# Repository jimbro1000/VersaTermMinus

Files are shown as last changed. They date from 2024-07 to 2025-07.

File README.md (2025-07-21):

# VersaTermMinus

Reduced and simplified version of David Hansel's VersaTerm
project [github.com/dhansel/VersaTerm](https://github.com/dhansel/VersaTerm)

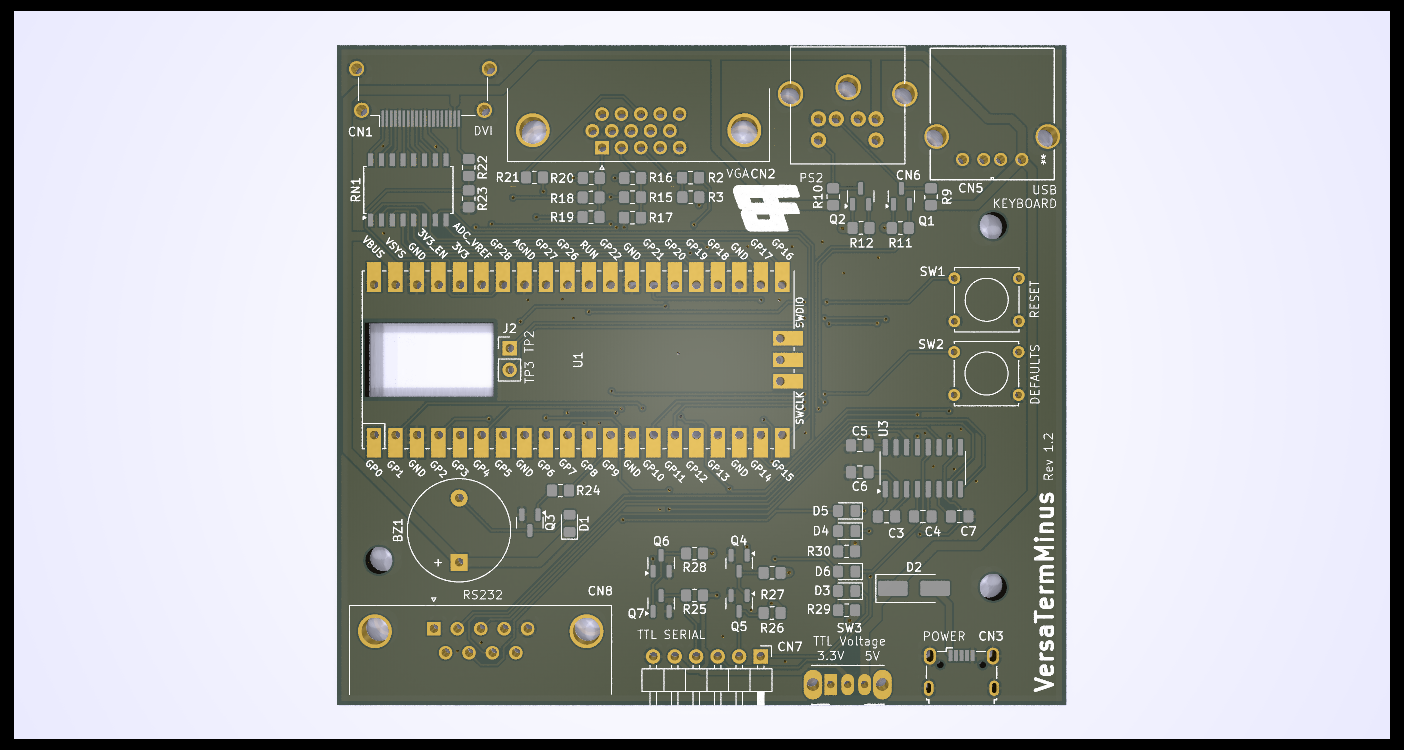
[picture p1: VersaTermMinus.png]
render of VersaTermMinus PCB


You can order PCBs for this project direct from PCBWay's shared projects
(https://www.pcbway.com/project/shareproject/VersaTermMinus_d8ad71ad.html)

## Changes to the Original Design

There are four significant changes to the board:

1. The barrel-jack power supply connection is deleted
2. The USB socket for keyboard is now micro-USB
3. The MAX3232 is integrated into the board
4. Where possible components are SMD

The changes allow the board to be reduced in size and cost.

## Assembly

It is highly recommended to use a stencil and
hot plate for mounting the SMD components. If
assembling by hand, start with the MAX232 chip
and resistor pack. It is important to mount the
small resistors, capacitors and diodes before
adding the HDMI, USB and large through-hole
components. Failing to do those first will make
assembly much harder.

If you want to use the USB keyboard option a
pair of wires needs to be attached to TP2 and
TP3 on the underside of the Pico board, and
connected to the J2 position on the main board.
Pin 1 of J2 should be connected to TP2.

### 1n4148 Diodes

The board uses a regular 0805 footprint for the
smaller 1n4148 diodes but it may prove easier
to source SOD323. These still fit easily on the
0805 footprint.

## Firmware

The pico board should be loaded with the 
original VersaTerm firmware from David Hansel's
git repository: [VersaTerm uf2 firmware](https://github.com/dhansel/VersaTerm/blob/main/software/VersaTerm.uf2)

## Errors on Early Fabricated Boards

On the first run of the board the traces to
the RS232 DE9 connector were incorrect. To fix
the error it is necessary to cut three of the
traces running from the MAX232 chip to the DE9.

With the DE9 nearest you the top three diagonal
traces running from top right to bottom left
need to be cut.

Three wires then need soldering to the upper two
pins of the DE9 and the lower middle (Pins 2, 3
and 8 of the connector). These need to be wired
to the MAX3232 on pins 5, 15 and 16.

DE9 pin 8 -> MAX3232 pin 16  
DE9 pin 2 -> MAX3232 pin 5  
DE9 pin 3 -> MAX3232 pin 15

To keep the fix tidy I drilled a hold through
the PCB above the right hand edge of the DE9
and below the visible traces on the top of the
board. This allows shorter, more direct
connections to be made.

A second fault exists within the buzzer circuit.
The polarity marking for the buzzer is reversed
(just fit the buzzer back to front). The transistor
switching the buzzer is also incorrect. To fix this
the transistor needs rotating around the top left 
pad (pin 2) such that the top right pin (1) sits on
the bottom pad. A wire needs to be run from the now
loose pin of the transistor (pin 3) to the negative
side of the buzzer, the vacant transistor pad or
the top pad of D1. The trace running from transistor
to the buzzer could be exposed to allow a solder 
bridge to be created

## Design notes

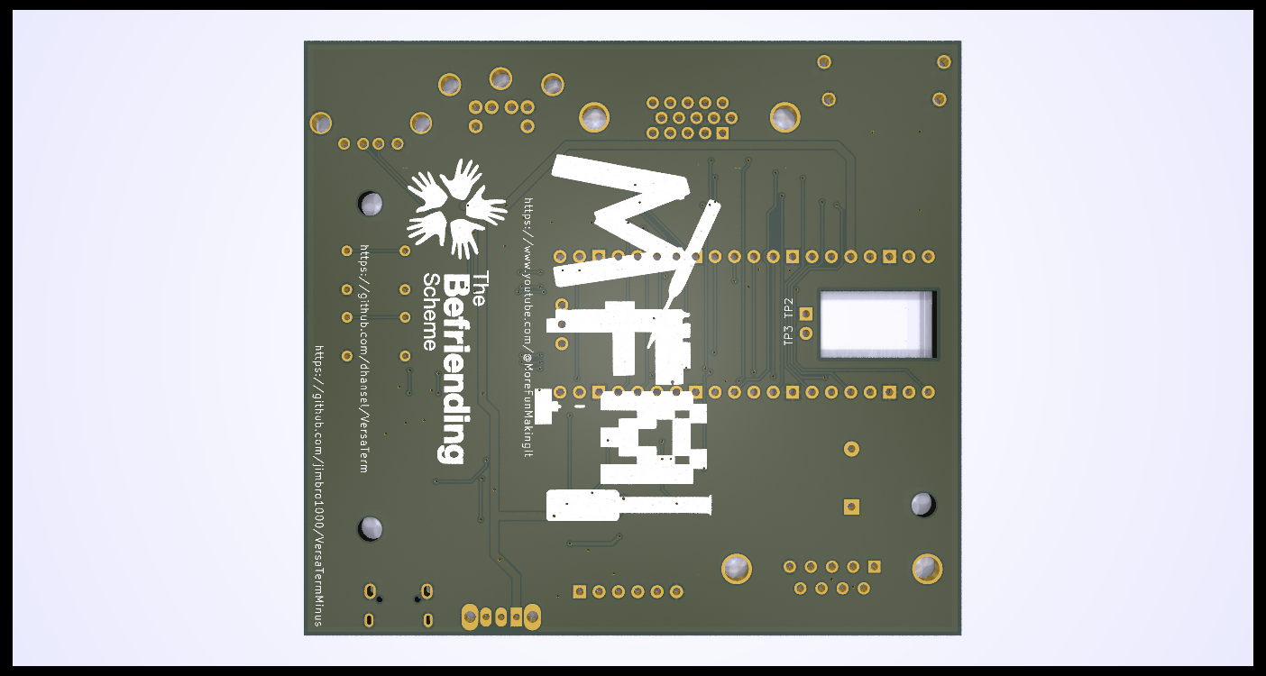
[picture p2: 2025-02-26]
VersaTermMinusBack.png

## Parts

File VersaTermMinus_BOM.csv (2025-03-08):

Reference | Value | Datasheet | Footprint | Qty | DNP
BZ1 | Buzzer | ~ | Buzzer_Beeper:Buzzer_12x9.5RM7.6 | 1
C3,C4,C5,C6,C7 | 100nF | ~ | Capacitor_SMD:C_0805_2012Metric_Pad1.18x1.45mm_HandSolder | 5
CN1 | HDMI_A | https://en.wikipedia.org/wiki/HDMI | Connector_HDMI:HDMI_A_Amphenol_10029449-x01xLF_Horizontal | 1
CN2 | DE15_Socket | ~ | Connector_Dsub:DSUB-15-HD_Female_Horizontal_P2.29x1.98mm_EdgePinOffset3.03mm_Housed_MountingHolesOffset4.94mm | 1
CN3 | USB_B_Micro | https://www.we-online.com/katalog/datasheet/629105150521.pdf | Connector_USB:USB_Micro-B_Wuerth_629105150521 | 1
CN5 | USB-A | 676432911 | Connector_USBA_Molex:CONN_67643-2911_MOL | 1
CN6 | Mini-DIN-6 | http://service.powerdynamics.com/ec/Catalog17/Section%2011.pdf | Connector_Mini_DIN:KMDGX-6S-N | 1
CN7 | TTL Serial | ~ | Connector_PinHeader_2.54mm:PinHeader_1x06_P2.54mm_Horizontal | 1
CN8 | DE9 Socket | ~ | Connector_Dsub:DSUB-9_Male_Horizontal_P2.77x2.84mm_EdgePinOffset4.94mm_Housed_MountingHolesOffset7.48mm | 1
D1,D3,D4,D5,D6 | 1N4148 | https://assets.nexperia.com/documents/data-sheet/1N4148_1N4448.pdf | Diode_SMD:D_0805_2012Metric_Pad1.15x1.40mm_HandSolder | 5
D2 | DBA140SL-HF | ~ | Diode_SMD:D_SMA_Handsoldering | 1
J2 | USBDATA | ~ | Connector_PinHeader_2.54mm:PinHeader_1x02_P2.54mm_Vertical | 1
Q1,Q2,Q3,Q4,Q5,Q6,Q7 | 2N7002 | https://www.onsemi.com/pub/Collateral/NDS7002A-D.PDF | Package_TO_SOT_SMD:SOT-23 | 7
R2,R17,R20,R25,R26 | 470R | ~ | Resistor_SMD:R_0805_2012Metric_Pad1.20x1.40mm_HandSolder | 5
R3,R16,R19,R27,R28,R29,R30 | 1K | ~ | Resistor_SMD:R_0805_2012Metric_Pad1.20x1.40mm_HandSolder | 7
R9,R10,R11,R12,R23 | 10K | ~ | Resistor_SMD:R_0805_2012Metric_Pad1.20x1.40mm_HandSolder | 5
R15,R18 | 2K2 | ~ | Resistor_SMD:R_0805_2012Metric_Pad1.20x1.40mm_HandSolder | 2
R21,R24 | 100R | ~ | Resistor_SMD:R_0805_2012Metric_Pad1.20x1.40mm_HandSolder | 2
R22 | 4K7 | ~ | Resistor_SMD:R_0805_2012Metric_Pad1.20x1.40mm_HandSolder | 1
RN1 | 270R | https://www.bourns.com/docs/Product-Datasheets/4800P.pdf | Package_SO:SOIC-16W_5.3x10.2mm_P1.27mm | 1
SW1 | RESET | https://www.ckswitches.com/media/1457/ksa_ksl.pdf | Button_Switch_THT:SW_Tactile_Straight_KSA0Axx1LFTR | 1
SW2 | DEFAULTS | https://www.ckswitches.com/media/1457/ksa_ksl.pdf | Button_Switch_THT:SW_Tactile_Straight_KSA0Axx1LFTR | 1
SW3 | 3V3/5V | https://www.ckswitches.com/media/1428/os.pdf | Button_Switch_THT:SW_Slide_SPDT_Angled_CK_OS102011MA1Q | 1
U1 | Raspberry Pi Pico |  | MCU_RaspberryPi_and_Boards:RPi_Pico_SMD_TH | 1
U3 | MAX3232 | https://datasheets.maximintegrated.com/en/ds/MAX3222-MAX3241.pdf | Package_SO:SOIC-16_3.9x9.9mm_P1.27mm | 1

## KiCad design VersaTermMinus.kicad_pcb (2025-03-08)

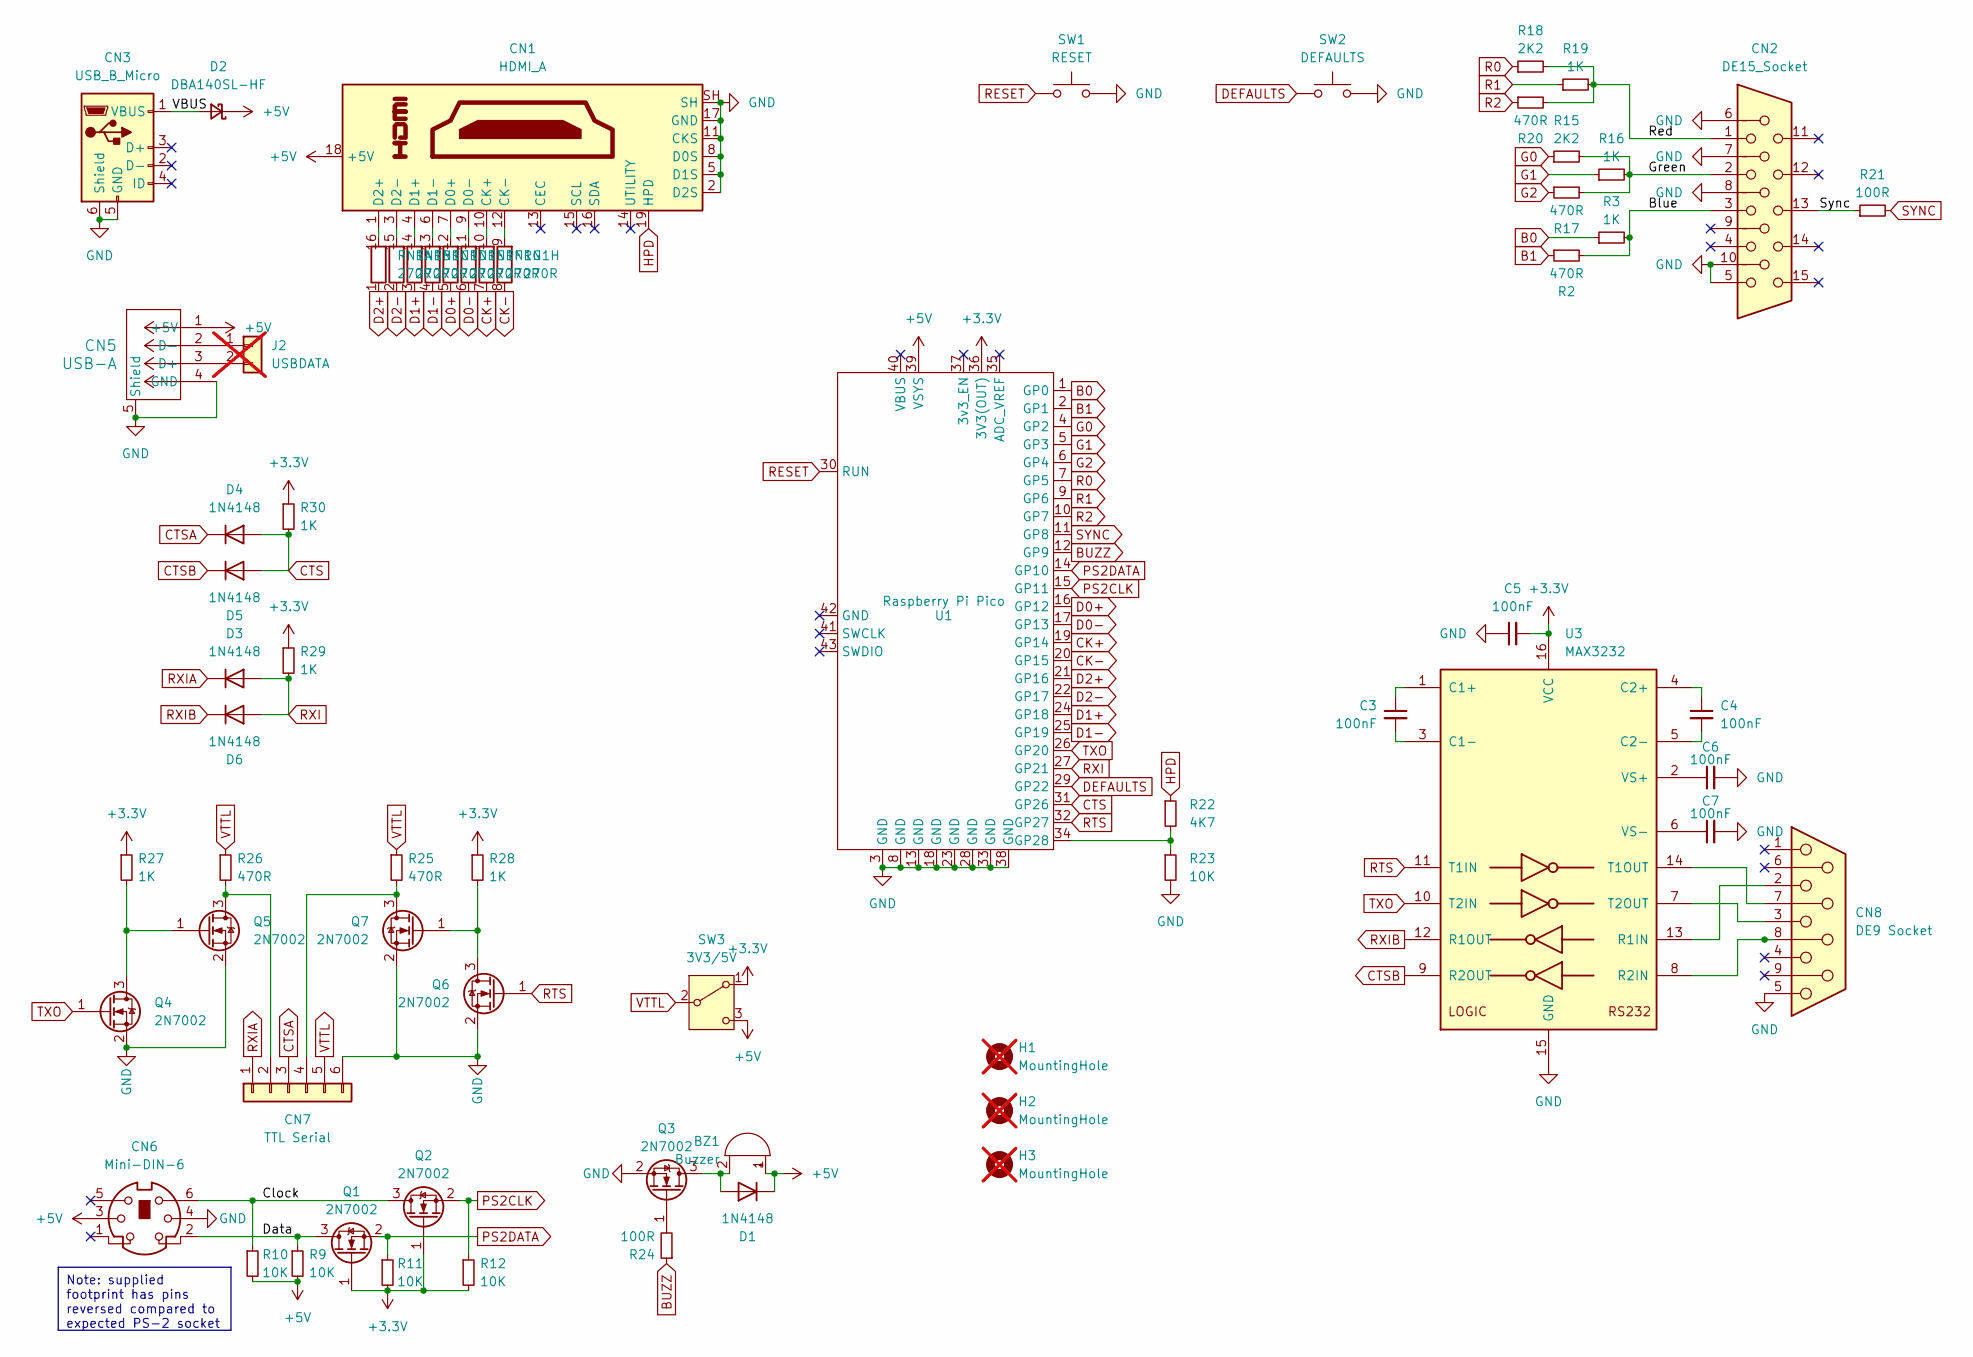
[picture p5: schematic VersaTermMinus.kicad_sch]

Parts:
BZ1: Buzzer; Buzzer_12x9.5RM7.6; LCSC C96491
C3, C4, C5, C6, C7: 100nF; C_0805_2012Metric_Pad1.18x1.45mm_HandSolder; DigiKey 311-1140-1-ND
CN1: HDMI_A; HDMI_A_Amphenol_10029449-x01xLF_Horizontal; DigiKey 609-4614-1-ND
CN2: DE15_Socket; DSUB-15-HD_Female_Horizontal_P2.29x1.98mm_EdgePinOffset3.03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; DigiKey L77HDE15SD1CH4FVGA-ND
CN3: USB_B_Micro; USB_Micro-B_Wuerth_629105150521; DigiKey 732-5960-1-ND
CN5: USB-A; CONN_67643-2911_MOL; DigiKey WM4078-ND
CN6: Mini-DIN-6; KMDGX-6S-N; DigiKey 2092-KMDGX-6S-BS-ND
CN7: TTL Serial; PinHeader_1x06_P2.54mm_Horizontal; LCSC C492414
CN8: DE9 Socket; DSUB-9_Male_Horizontal_P2.77x2.84mm_EdgePinOffset4.94mm_Hou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; DigiKey AE10968-ND
D1, D3, D4, D5, D6: 1N4148; D_0805_2012Metric_Pad1.15x1.40mm_HandSolder; DigiKey 1N4148WXTPMSCT-ND
D2: DBA140SL-HF; D_SMA_Handsoldering; DigiKey 641-1762-1-ND
H1, H2, H3: MountingHole; MountingHole_3.2mm_M3; not fitted
J2: USBDATA; PinHeader_1x02_P2.54mm_Vertical; not fitted
Q1, Q2, Q3, Q4, Q5, Q6, Q7: 2N7002; SOT-23; DigiKey 2N7002NCT-ND
R2, R17, R20, R25, R26: 470R; R_0805_2012Metric_Pad1.20x1.40mm_HandSolder; DigiKey RMCF0805FT470RCT-ND
R3, R16, R19, R27, R28, R29, R30: 1K; R_0805_2012Metric_Pad1.20x1.40mm_HandSolder; LCSC C95781
R9, R10, R11, R12, R23: 10K; R_0805_2012Metric_Pad1.20x1.40mm_HandSolder; LCSC C17414
R15, R18: 2K2; R_0805_2012Metric_Pad1.20x1.40mm_HandSolder; LCSC C17520
R21, R24: 100R; R_0805_2012Metric_Pad1.20x1.40mm_HandSolder; LCSC C105577
R22: 4K7; R_0805_2012Metric_Pad1.20x1.40mm_HandSolder; LCSC C17673
RN1: 270R; SOIC-16W_5.3x10.2mm_P1.27mm; DigiKey 4816P-1-271LFCT-ND
SW1: RESET; SW_Tactile_Straight_KSA0Axx1LFTR; DigiKey CKN10734-ND
SW2: DEFAULTS; SW_Tactile_Straight_KSA0Axx1LFTR; DigiKey CKN10734-ND
SW3: 3V3/5V; SW_Slide_SPDT_Angled_CK_OS102011MA1Q; DigiKey CKN9559-ND
U1: Raspberry Pi Pico; RPi_Pico_SMD_TH
U3: MAX3232; SOIC-16_3.9x9.9mm_P1.27mm; DigiKey 296-13094-1-ND

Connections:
+3.3V: C5.2, Q1.1 (G), Q2.1 (G), R11.2, R12.2, R27.1, R28.1, R29.1, R30.1, SW3.1 (A), U1.36 (3V3(OUT)), U3.16 (VCC)
+5V: BZ1.1 (+), CN1.18 (+5V), CN5.1 (+5V), CN6.3, D1.1 (K), D2.1 (K), R9.2, R10.2, SW3.3 (C), U1.39 (VSYS)
/Blue: CN2.3, R2.2, R3.2
/Clock: CN6.6, Q2.3 (D), R10.1
/Data: CN6.2, Q1.3 (D), R9.1
/Green: CN2.2, R15.2, R16.2, R17.2
/Red: CN2.1, R18.2, R19.2, R20.2
/Sync: CN2.13, R21.1
/VBUS: CN3.1 (VBUS), D2.2 (A)
B0: R3.1, U1.1 (GP0)
B1: R2.1, U1.2 (GP1)
BUZZ: R24.1, U1.12 (GP9)
CK+: RN1.7 (R7.1), U1.19 (GP14)
CK-: RN1.8 (R8.1), U1.20 (GP15)
CTS: D4.2 (A), D5.2 (A), R30.2, U1.31 (GP26)
CTSA: CN7.3, D4.1 (K)
CTSB: D5.1 (K), U3.9 (R2OUT)
D0+: RN1.5 (R5.1), U1.16 (GP12)
D0-: RN1.6 (R6.1), U1.17 (GP13)
D1+: RN1.3 (R3.1), U1.24 (GP18)
D1-: RN1.4 (R4.1), U1.25 (GP19)
D2+: RN1.1 (R1.1), U1.21 (GP16)
D2-: RN1.2 (R2.1), U1.22 (GP17)
DEFAULTS: SW2.1, U1.29 (GP22)
G0: R15.1, U1.4 (GP2)
G1: R16.1, U1.5 (GP3)
G2: R17.1, U1.6 (GP4)
GND: C5.1, C6.2, C7.2, CN1.2 (D2S), CN1.5 (D1S), CN1.8 (D0S), CN1.11 (CKS), CN1.17 (GND), CN1.SH, CN2.5, CN2.6, CN2.7, CN2.8, CN2.10, CN3.5 (GND), CN3.6 (Shield), CN5.4 (GND), CN5.5 (Shield), CN6.4, CN7.6, CN8.5, Q3.2 (S), Q4.2 (S), Q5.2 (S), Q6.2 (S), Q7.2 (S), R23.2, SW1.2, SW2.2, U1.3 (GND), U1.8 (GND), U1.13 (GND), U1.18 (GND), U1.23 (GND), U1.28 (GND), U1.33 (GND), U1.38 (GND), U3.15 (GND)
HPD: CN1.19 (HPD), R22.1
unnamed: BZ1.2 (-), D1.2 (A), Q3.3 (D)
unnamed: CN1.10 (CK+), RN1.10 (R7.2)
unnamed: CN1.12 (CK-), RN1.9 (R8.2)
unnamed: CN1.7 (D0+), RN1.12 (R5.2)
unnamed: CN1.9 (D0-), RN1.11 (R6.2)
unnamed: CN1.4 (D1+), RN1.14 (R3.2)
unnamed: CN1.6 (D1-), RN1.13 (R4.2)
unnamed: CN1.1 (D2+), RN1.16 (R1.2)
unnamed: CN1.3 (D2-), RN1.15 (R2.2)
unnamed: CN5.3 (D+), J2.2
unnamed: CN5.2 (D-), J2.1
unnamed: CN7.2, Q5.3 (D), R26.2
unnamed: CN7.4, Q7.3 (D), R25.2
unnamed: Q3.1 (G), R24.2
unnamed: Q4.3 (D), Q5.1 (G), R27.2
unnamed: Q6.3 (D), Q7.1 (G), R28.2
unnamed: R22.2, R23.1, U1.34 (GP28)
unnamed: C3.1, U3.1 (C1+)
unnamed: C3.2, U3.3 (C1-)
unnamed: C4.1, U3.4 (C2+)
unnamed: C4.2, U3.5 (C2-)
unnamed: CN8.2, U3.13 (R1IN)
unnamed: CN8.8, U3.8 (R2IN)
unnamed: CN8.7, U3.14 (T1OUT)
unnamed: CN8.3, U3.7 (T2OUT)
unnamed: C6.1, U3.2 (VS+)
unnamed: C7.1, U3.6 (VS-)
PS2CLK: Q2.2 (S), R12.1, U1.15 (GP11)
PS2DATA: Q1.2 (S), R11.1, U1.14 (GP10)
R0: R18.1, U1.7 (GP5)
R1: R19.1, U1.9 (GP6)
R2: R20.1, U1.10 (GP7)
RESET: SW1.1, U1.30 (RUN)
RTS: Q6.1 (G), U1.32 (GP27), U3.11 (T1IN)
RXI: D3.2 (A), D6.2 (A), R29.2, U1.27 (GP21)
RXIA: CN7.1, D3.1 (K)
RXIB: D6.1 (K), U3.12 (R1OUT)
SYNC: R21.2, U1.11 (GP8)
TXO: Q4.1 (G), U1.26 (GP20), U3.10 (T2IN)
VTTL: CN7.5, R25.1, R26.1, SW3.2 (B)

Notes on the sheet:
Note: supplied footprint has pins reversed compared to expected PS-2 socket

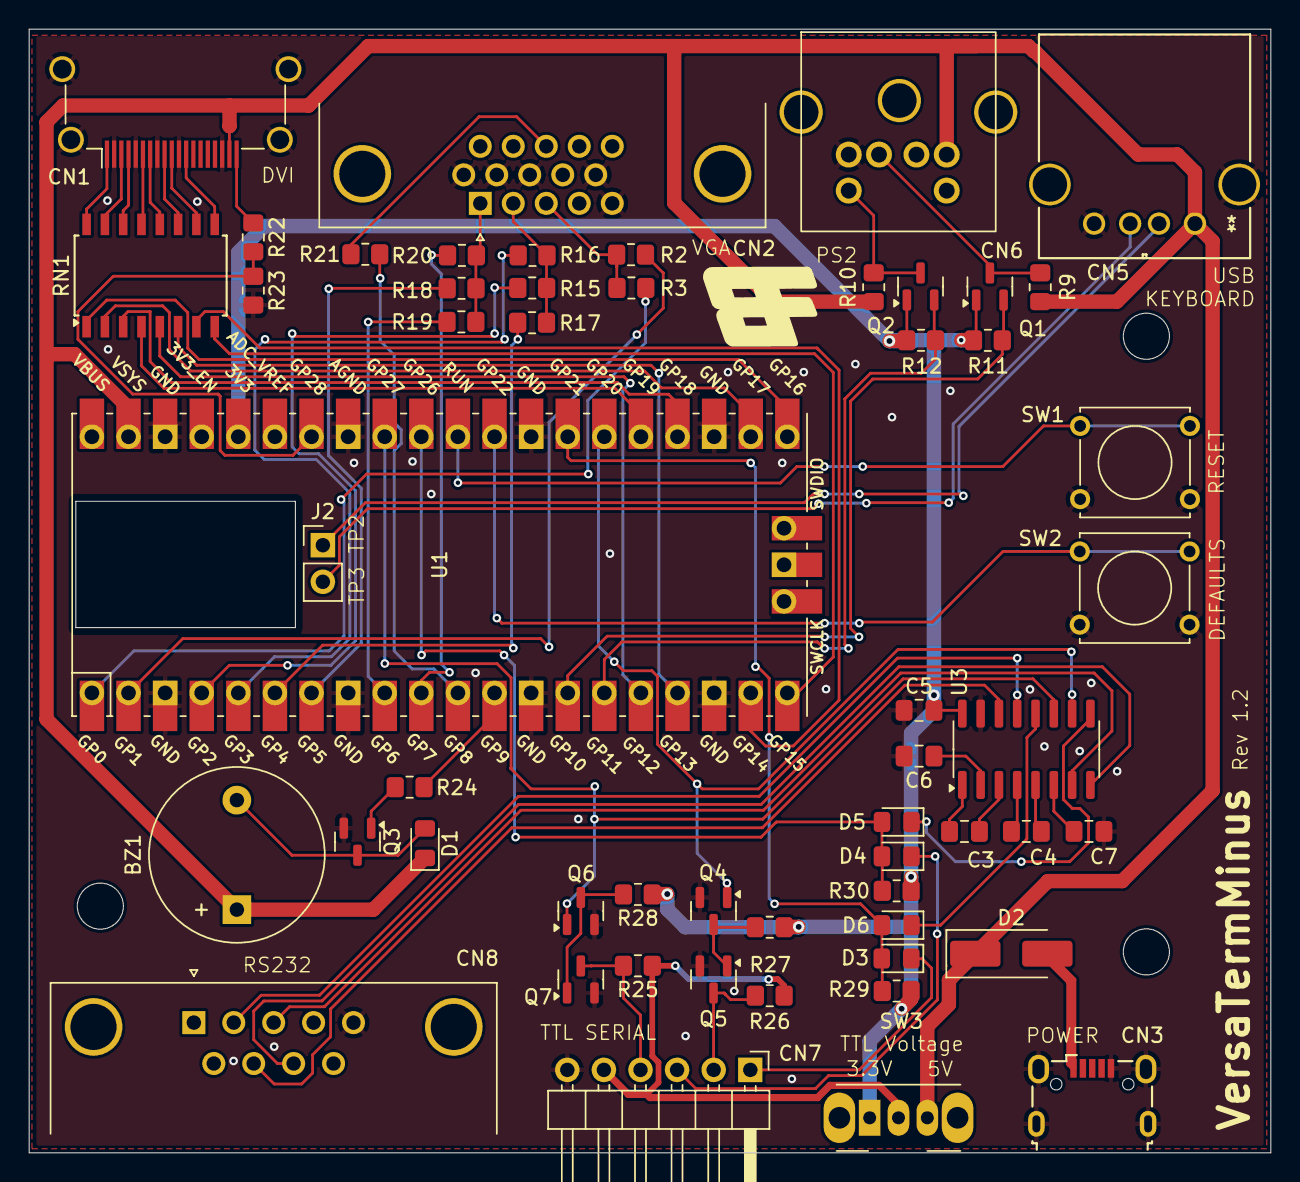
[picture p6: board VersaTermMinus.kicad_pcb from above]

Board: 2 copper layers, 86.2 x 78.0 mm, 58 parts (0 on the bottom side), 69 nets.

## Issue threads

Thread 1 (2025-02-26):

Extra frame on the edge-cut layer that overlaps with holes of drill layer

neilbartlett, 2025-02-26:
The frame is indicated by the yellow arrow.

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

I believe the frame is not necessary, but the drill holes are!

jimbro1000, 2025-02-26:
Thanks for the feedback!

The drill holes are actually reference points for the Pico - they align with the USB port but offer no benefit that I can determine beyond some relief to make sure the Pico sits flat. Why these are included on the reference footprint of the Pico is odd but I've not questioned it or attempted to modify the footprint.  The previous version of the board had the drill holes and gained nothing from it.

Ironically there are 4 possible drill holes for mechanically mounting the Pico that are not included in the standard footprint

The cut-out on the other hand is absolutely essential in order to mount the Pico directly to the board and still provide access to the test points used to pass through the USB connection to J2. Those test points sit in-between the two larger drill holes so I could possibly narrow the frame but I don't believe it would help with anything

neilbartlett, 2025-02-26:
BTW unless not clear. I was manufacturing at PCBWay when they pointed out this issue.

jimbro1000, 2025-02-26:
"I can simply raise the pico board on some extra headers when soldering it to allow space and prewire the jumpers - that is if I want to use the USB board jumper connections which I believe is the purpose of the test point connections?"

That is what I've done on my personal board as it lets me reuse the Pico for other tasks without a massive de-soldering job :D

I will modify the Pico footprint to remove the ambiguous drill holes and avoid challenges

jimbro1000, 2025-02-26:
I've modified the footprint to bypass the problem and avoid awkward questions from PCB fabricators

The project has now been shared on PCBWay to streamline the ordering process

neilbartlett, 2025-02-26:
👍👍

Closed 2025-02-26.

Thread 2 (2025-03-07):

Please update the BOM

zymurgy, 2025-03-07:
Please update the BOM.  CN5 is a Molex USB-A 67643-2911, not a micro USB.  If you order parts off the BOM you will be missing parts.

jimbro1000, 2025-03-07:
On the last two revisions of the board CN5 *is* a USB-A instead of a micro USB. The versions of the board that used a micro-USB in that position have issues that require careful modification to make them work. Only the most recent revision has been released, please make sure you are referring to the release files.

I am happy to make corrections still

jimbro1000, 2025-03-08:
I've revisited the BOM, just in case I was talking rubbish
The USB connection at CN5 is definitely correct but I've added alternative part numbers through LCSC for all parts except the Pico itself

Closed 2025-03-08.

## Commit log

2024-06-09 add silkscreen labelling
    [VersaTermMinus.kicad_pcb]
2024-06-20 record digikey part numbers
    [VersaTermMinus.kicad_sch]
2024-06-20 update fields on pcb
    [VersaTermMinus.kicad_pcb]
2024-07-02 fix de9 and buzzer
    [VersaTermMinus.kicad_pcb, VersaTermMinus.kicad_sch]
2024-07-09 populate missing BOM fields
    [VersaTermMinus.kicad_pcb, VersaTermMinus.kicad_sch]
2024-07-12 fix incorrect schema symbols for 2n7002 transistors
    [VersaTermMinus.kicad_pcb, VersaTermMinus.kicad_sch]
2025-02-19 version 1.1
    [VersaTermMinus.kicad_pcb, VersaTermMinus.kicad_sch]
2025-02-19 update board renders
2025-02-26 add TP labels to back silkscreen
    [VersaTermMinus.kicad_pcb, VersaTermMinus.kicad_sch]
2025-02-26 remove ambiguous drill holes
    [VersaTermMinus.kicad_pcb]
2025-03-08 update BOM supplier part numbers
    [VersaTermMinus.kicad_pcb, VersaTermMinus.kicad_sch, VersaTermMinus_BOM.csv]
